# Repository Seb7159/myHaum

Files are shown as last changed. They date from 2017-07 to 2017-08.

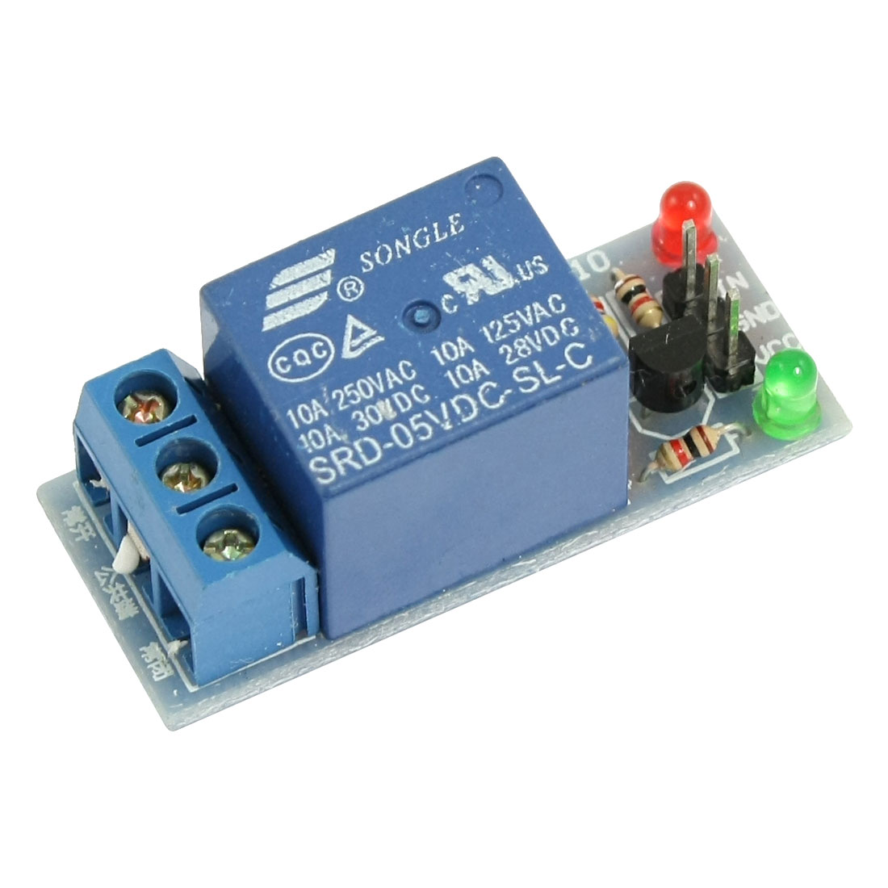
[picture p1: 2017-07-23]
web/form/map/img/9.jpg

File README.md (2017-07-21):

# myHaum

A project which adds tons of sensors in one product in order to serve one's home security.

## Getting Started

These instructions will get you a copy of the project up and running on your local Arduino micro-controller for development and testing purposes. See deployment for notes on how to deploy the project on a live system.

### Prerequisites

What things you need to install the software and how to install them

```
Arduino IDE
Arduino Mega 2560 micro-controller
WinSCP/Total Commander(FTP client)
Sublime text(optional)
```

### Installing

A step by step series of examples that tell you have to get a development env running

Add the sensors needed (those you can observe in the code)

```
DHT11
MQ2 Gas sensor
Photoresistor
PIR Motion sensor
LCD display
2 buttons
ESP8266-01 WiFi module
Passive buzzer
```

Make sure you edit the WiFi name and password 

```
Default WiFi name: H218N
Default WiFi pass: certificat
```

Put the /web files on your server

```
display.php
AppDisplay.php
/get files
```

IMPORTANT! Don't forget to change the passwords and the usernames to yours 

Hopefully this will work out for you. 

## Running the tests

Test it by keeping it on for as long as you want. 

### Break down into end to end tests

Tests are for finding bugs during the using period of the product, including the web applications.

## Deployment

To deploy the arduino part, you need to download the folder /temp (or /light), connect your Arduino with the connected sensors to the pins you have in the source code, then Run it by pressing the Arduino IDE button. 

To deploy the server files, connect to your server using a FTP program (I use WinSCP or Total Commander) and upload them there. 

## Built With

* [Arduino](https://www.arduino.cc/) - The micro-controller framework used
* [ESP8266](https://espressif.com/en/products/hardware/esp8266ex/overview) - Used to send data to the SQL server thorugh the ESP8266-01 module
* [Fixed table header](https://codepen.io/nikhil8krishnan/full/WvYPvv/) - Design for tables insine the display application 
* [NodeMCU firmware](https://github.com/nodemcu/nodemcu-firmware) - Big parts of code from the light's .ino source 
* [Codrops](https://github.com/nodemcu/codrops) - Main website was created using several ideas of his, realised for the front-end part (ButtonComponentMorph,MorphingBackgroundShapes,FullscreenForm,InteractivePoints) 

## Versioning

We use [GitHub](http://github.com/) for versioning. For the versions available, see the commits from this project (https://github.com/Seba7159/myHaum). 

## Authors

* **Sebastian Stanici** - *Initial work* - [Seba7159](https://github.com/Seba7159)

## License

This project is licensed under the MIT License - see the [LICENSE.md](LICENSE.md) file for details

## Acknowledgments

* One's name who finds bug fixes and contribues will have his name on the contributors list
* Was inspired by all the news following the problems with companies spying on clients, this project is for one's own use and myHaum team will never use your data, keeping it safe and secure

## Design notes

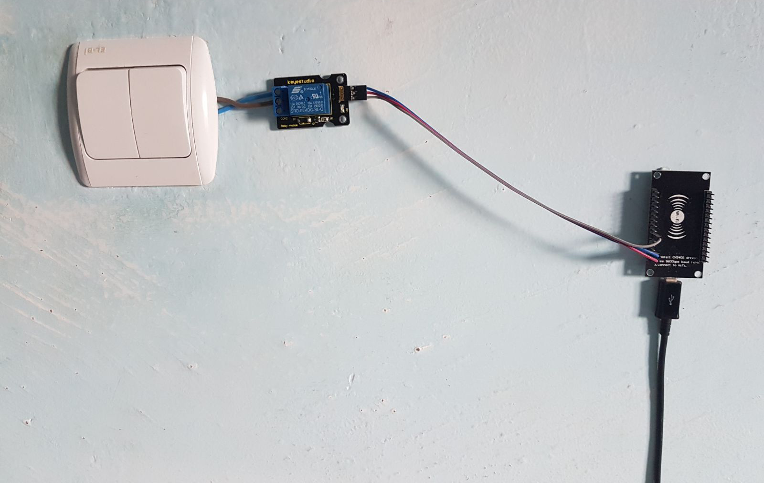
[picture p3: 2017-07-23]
web/form/map/img/map2.png

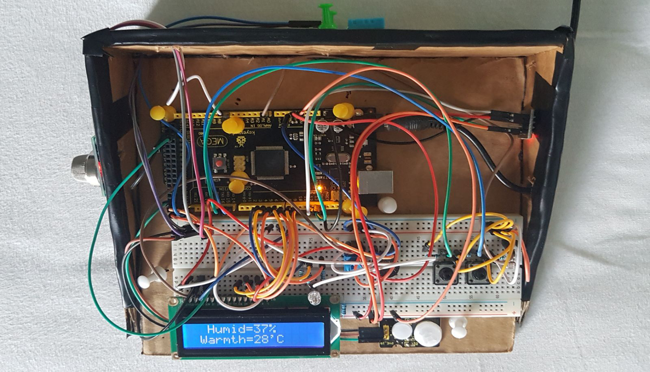
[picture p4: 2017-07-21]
web/form/map/img/map.png

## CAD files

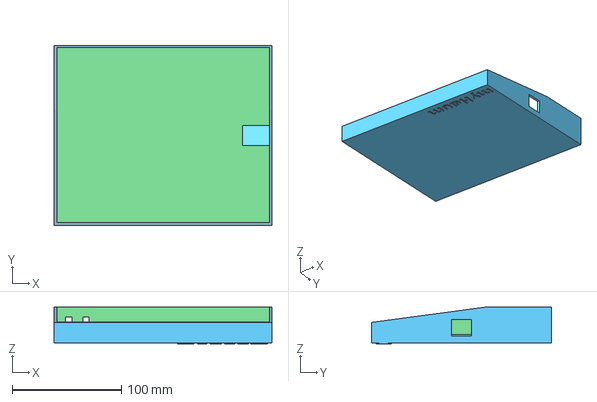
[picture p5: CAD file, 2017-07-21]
3Dprint/myHaum3DPrint1703303DBuilder.3mf
200.0 x 165.0 x 33.9 mm

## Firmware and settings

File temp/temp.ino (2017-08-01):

#include <Arduino.h>                   // the libraries 
#include <SoftwareSerial.h>
#include <ESP8266_Simple.h>
#include <LiquidCrystal.h> 
#include <DHT.h> 

#define DEBUG 1                         // if DEBUG is 1, the arduino will print data on Serial 

#define PHOTOpin A0                     // analog photoresistor 
#define GASpin A7                       // analog gas 
#define PIRsensorPin 24                 // digital PIR  
#define pBlu 3                          // digital blue LED 
#define pGrn 4                          // digital green LED
#define pRed 5                          // digital red LED 
#define ESP8266_SSID  "H218N"           // WiFi SSID
#define ESP8266_PASS  "certificat"      // WiFi Password
#define RXpinSEND 12                    // ESP-01 wifiSEND module TX
#define TXpinSEND 13                    // ESP-01 wifiSEND module RX 
#define RELAYbutton 15                  // digital switch 1
#define ALARMbutton 14                  // digital switch 2 
#define DHTpin 21                       // digital temp sensor  
#define BUZZpin 22                      // digital buzzer 

#define REFRESHupload 30                // seconds to upload data to database / to be changed to 15 min

LiquidCrystal lcd(11, 10, 6, 7, 8, 9);  // actual pins for LCD displaying content 
ESP8266_Simple wifiSEND( RXpinSEND, TXpinSEND); 
DHT dht( DHTpin, DHT11); 

byte doo[8] = {                         // set 7 frames of an animation in a LCD square when loading                 
  B00000,
  B00000,
  B00000,
  B00000,
  B00000,
  B10000,
  B11000,
};
byte re[8] = {
  B00000,
  B00000,
  B00000,
  B10000,
  B11000,
  B11100,
  B11110,
};
byte mi[8] = {
  B00000,
  B00000,
  B10000,
  B11000,
  B11100,
  B11100,
  B11111,
};
byte fa[8] = {
  B00000,
  B10000,
  B11000,
  B11100,
  B11110,
  B11111,
  B11111,
};
byte sol[8] = {
  B10000,
  B11000,
  B11100,
  B11110,
  B11111,
  B11111,
  B11111,
};
byte la[8] = {
  B11100,
  B11110,
  B11111,
  B11111,
  B11111,
  B11111,
  B11111,
};
byte si[8] = {
  B11111,
  B11111,
  B11111,
  B11111,
  B11111,
  B11111,
  B11111,
};
byte deg[8] = {
  B000111,
  B00101,
  B00111,
  B00000,
  B00000,
  B00000,
  B00000,
};









void setup(){
  lcd.createChar(1,doo);                  // create the animation frames by the micro-controller 
  lcd.createChar(2,re); 
  lcd.createChar(3,mi); 
  lcd.createChar(4,fa); 
  lcd.createChar(5,sol); 
  lcd.createChar(6,la); 
  lcd.createChar(7,si);
  lcd.createChar(8,deg); 
  
  lcd.begin(16, 2);                   
  lcd.setCursor(0,0); 
  lcd.print("Loading...             "); 
  
  int loadTime = 0;                       // begin animation 
  loadScreen(loadTime); loadTime++;  
  pinMode(pRed, OUTPUT);                  // set pin layout for arduino sending input and obtaining output 
  pinMode(pGrn, OUTPUT); 
  pinMode(pBlu, OUTPUT); 
  pinMode(PIRsensorPin,INPUT); 
  pinMode(ALARMbutton,INPUT); 
  pinMode(RELAYbutton,INPUT); 
  pinMode(BUZZpin, OUTPUT); 
  Serial.begin(9600); 
  wifiSEND.begin(9600); loadScreen(loadTime); loadTime++;                  // start WiFi module 
  

  lcd.setCursor(0,0); lcd.print("Resetting...             ");
  for( loadTime = 2 ; loadTime < 6; ++loadTime)
    loadScreen(loadTime); 

  char bufferr[300]; 
  wifiSEND.sendCommand(F("AT"), bufferr, sizeof(bufferr)); delay(50); 
  if(DEBUG) 
    Serial.println(bufferr);

  for( loadTime = 6 ; loadTime < 7; ++loadTime)
    loadScreen(loadTime); 

    
  wifiSEND.sendCommand(F("AT+CWJAP?"), bufferr, sizeof(bufferr));
  delay(100); 
  if(DEBUG){ 
    Serial.println(bufferr);
    Serial.println(ESP8266_SSID);     
  }

  for( loadTime = 7 ; loadTime < 10; ++loadTime)
    loadScreen(loadTime); 

  if(bufferr[0]!=ESP8266_SSID[0] || bufferr[1]!=ESP8266_SSID[1] || bufferr[2]!=ESP8266_SSID[2]){          // test if the ESP is already connected to previous WiFi 
  wifiSEND.sendCommand(F("AT+RST"), bufferr, sizeof(bufferr));                 // reset WiFi module 
  delay(2000); 
  wifiSEND.setupAsWifiStation(ESP8266_SSID, ESP8266_PASS, &Serial);            // connect to the WiFi with the set ssid and password 
  delay(5000); 
  }
  
  lcd.setCursor(0,0); lcd.print("Connecting...             "); 
  for( loadTime = 10 ; loadTime < 16; ++loadTime)
    loadScreen(loadTime); 
  lcd.setCursor(0,1); 
  lcd.print(" Ready!            ");
  delay(800); 
}








int alarm=0,lightBulb=0;                                                   // set booleans for alarm and lightBulb if they are on/off 
unsigned long WIFIupload = -REFRESHupload ,LASTmotion = 0;                 // set timeout for wifi uploading and last motion sensed 




void ifPressButton(){                                       // function for seeing if rhe buttons are pressed 
  if(digitalRead(ALARMbutton)){                                                 // event if alarm button(2) is pushed 
    alarm++; alarm=alarm%2; 
    if(DEBUG) Serial.print("Alarm is "); if(DEBUG) Serial.println(alarm);  
    if(alarm){
      
      lcd.setCursor(0,0); lcd.print("House will be         "); 
      lcd.setCursor(0,1); lcd.print(" armed in         "); 
      delay(400); 
      
      for( int i = 19 ; i>=0 ; --i ){
        lcd.setCursor(12,1);
        if(i<10) lcd.setCursor(11,1);
        lcd.print(i); lcd.print("         "); 

        setColor(40,0,0);
        delay(100); 
        setColor(0,0,0); 
        int ok=0; 
        
        for(int i=0;i<9;i++){
          if(digitalRead(ALARMbutton)){
            alarm++; alarm=alarm%2; 
            if(DEBUG) Serial.print("Alarm is "); if(DEBUG) Serial.println(alarm);  
            ok=1; 
            break; 
          }
          delay(100); 
        }
        if(ok==1)
          break; 
      }
      if(alarm){
        lcd.setCursor(0,0); 
        lcd.print("House is now       "); 
        lcd.setCursor(0,1); 
        lcd.print("      ARMED!          "); 
        setColor(255,0,0); 
        }
      else{
        lcd.setCursor(0,0); 
        lcd.print("House is now       "); 
        lcd.setCursor(0,1); 
        lcd.print("    UNARMED!           "); 
        setColor(0,0,255); 
      }
    }
    else{
      lcd.setCursor(0,0); 
      lcd.print("House is now       "); 
      lcd.setCursor(0,1); 
      lcd.print("    UNARMED!          "); 
      setColor(0,0,255); 
    } 
    delay(2000); 
    setColor(0,0,0); 
  }
  


  if(digitalRead(RELAYbutton)){                                                                // event if light bulb button(1) is pushed 
    lightBulb++; lightBulb=lightBulb%2; 
    if(DEBUG) Serial.print("The light bulb is "); if(DEBUG) Serial.println(lightBulb); 
    if(lightBulb){
      lcd.setCursor(0,0); 
      lcd.print("Light bulb                "); 
      lcd.setCursor(0,1); 
      lcd.print("         ON!          "); 
      setColor(255,255,255); 
    }
    else{
      lcd.setCursor(0,0); 
      lcd.print("Light bulb          "); 
      lcd.setCursor(0,1); 
      lcd.print("         OFF!     "); 
      setColor(0,0,0); 
    }
    delay(900); 
  }  
}


void loop()                                                                // start a new cycle
{  
  if(DEBUG) Serial.println("Starting new cycle");                           


  
  if(DEBUG) Serial.print("Gas value is ");                                 // read gas and alarm if gas levels are too high ( over 45% = gas leaks, over 50% = hazardous environment ) 
  if(DEBUG) Serial.println(analogRead(GASpin)); 
  if(analogRead(GASpin)>450){
      if(analogRead(GASpin)>500){
        lcd.setCursor(0,0); 
        lcd.print(" WARNING! GAS"); 
        lcd.setCursor(0,1); 
        lcd.print("  LEVELS EXCEEDED!"); 
        tone(BUZZpin, 2000, 500); 
      }
      else{
        lcd.setCursor(0,0); 
        lcd.print(" WARNING! Gas"); 
        lcd.setCursor(0,1); 
        lcd.print("  leaks detected!"); 
      }

      char buffer[250];                                                                                  // send WiFi data in case of gas leaks (>25% gas levels)

      memcpy(buffer, 0, sizeof(buffer));     
      strncpy_P(buffer, PSTR("/get/getgas.php?p=abc"), sizeof(buffer)-1);
     
      strncpy_P(buffer+strlen(buffer), PSTR("&lastg="), sizeof(buffer)-strlen(buffer)-1);
      ltoa(analogRead(GASpin), buffer+strlen(buffer), 10); 
        
      if(DEBUG) Serial.print("Requesting GAS");
      if(DEBUG) Serial.print(buffer);
      if(DEBUG) Serial.print(": ");
      
      unsigned int httpResponseCode = 
        wifiSEND.GET
        (
          F("86.123.250.85"),     
          80,                     
          buffer,                 
          sizeof(buffer),         
          F("seba.tm-edu.ro"), 
          2                       
                                   
                                  
        );
  
    if(httpResponseCode == 200 || httpResponseCode == ESP8266_OK){
      if(DEBUG) Serial.println("OK");
      if(DEBUG) Serial.println(buffer);
    }
    else
      if(httpResponseCode < 100) 
        wifiSEND.debugPrintError((byte)httpResponseCode, &Serial);
      else{
        if(DEBUG) Serial.print("HTTP Status ");
        if(DEBUG) Serial.println(httpResponseCode);
      }     
   
     delay(1000); 
  }
  else
    noTone(BUZZpin); 


  ifPressButton();


  if(digitalRead(PIRsensorPin)){                                                                 // event motion sense 
    if(DEBUG) Serial.println("Somebody is in this area!"); 
    LASTmotion=millis()/1000; 
    
    if(alarm==1){
      char buffer[250]; 
    
      memcpy(buffer, 0, sizeof(buffer));     
      strncpy_P(buffer, PSTR("/get/getmotion.php?p=abc"), sizeof(buffer)-1);
     
      strncpy_P(buffer+strlen(buffer), PSTR("&lastm="), sizeof(buffer)-strlen(buffer)-1);
      ltoa(millis()/1000, buffer+strlen(buffer), 10); 
        
      if(DEBUG) Serial.print("Requesting MOTION");
      if(DEBUG) Serial.print(buffer);
      if(DEBUG) Serial.print(": ");
      
      unsigned int httpResponseCode = 
        wifiSEND.GET
        (
          F("86.123.250.85"),     
          80,                     
          buffer,                 
          sizeof(buffer),         
          F("seba.tm-edu.ro"), 
          2                       
                                   
                                  
        ); 
      
      if(httpResponseCode == 200 || httpResponseCode == ESP8266_OK){
        if(DEBUG) Serial.println("OK");
        if(DEBUG) Serial.println(buffer);
      }
      else
        if(httpResponseCode < 100) 
          wifiSEND.debugPrintError((byte)httpResponseCode, &Serial);
        else{
          if(DEBUG) Serial.print("HTTP Status ");
          if(DEBUG) Serial.println(httpResponseCode);
        }
    }  
  }












  if(DEBUG){                                                 // print data to Serial if DEBUG = 1
    Serial.println("Brightness: "); // brightness   
    Serial.println(analogRead(PHOTOpin));  
    Serial.println(); 
    Serial.print("Temperature = "); // DHT 
    Serial.println(dht.readTemperature());
    Serial.print("Humidity = ");
    Serial.println(dht.readHumidity()); 
    Serial.println(); 
  }






  
  if(lightBulb==0){                                                                                // display different data wheter the light bulb is on or off 
    lcd.setCursor(0,0); 
    lcd.print("  Humid="); lcd.print((int)dht.readHumidity()); lcd.print("%            ");  
    lcd.setCursor(0,1); 
    lcd.print(" Warmth="); lcd.print((int)dht.readTemperature()); lcd.write(byte(8)); lcd.println("C            ");
  }
  else{
    lcd.setCursor(0,0); 
    lcd.print("Brightness: ");  
    lcd.print(analogRead(PHOTOpin)); 
    lcd.print("               "); 
    lcd.setCursor(0,1); 
    lcd.print("Gas: "); 
    lcd.print(analogRead(GASpin)); lcd.print("               "); 
  }









  if(WIFIupload+REFRESHupload<millis()/1000){                                                // send all the data from all the sensor over WiFi to SQL database  
    char buffer[250]; 
    
      memcpy(buffer, 0, sizeof(buffer));     
      strncpy_P(buffer, PSTR("/get/get.php?p=abc"), sizeof(buffer)-1);
     
      strncpy_P(buffer+strlen(buffer), PSTR("&temp="), sizeof(buffer)-strlen(buffer)-1);
      ltoa((int)dht.readTemperature(), buffer+strlen(buffer), 10); 

      strncpy_P(buffer+strlen(buffer), PSTR("&hum="), sizeof(buffer)-strlen(buffer)-1);
      ltoa((int)dht.readHumidity(), buffer+strlen(buffer), 10); 

      strncpy_P(buffer+strlen(buffer), PSTR("&gas="), sizeof(buffer)-strlen(buffer)-1);
      ltoa(analogRead(GASpin), buffer+strlen(buffer), 10); 

      strncpy_P(buffer+strlen(buffer), PSTR("&light="), sizeof(buffer)-strlen(buffer)-1);
      ltoa(analogRead(PHOTOpin), buffer+strlen(buffer), 10); 

      strncpy_P(buffer+strlen(buffer), PSTR("&ms="), sizeof(buffer)-strlen(buffer)-1);
      ltoa(millis()/1000, buffer+strlen(buffer), 10); 

      strncpy_P(buffer+strlen(buffer), PSTR("&lmdbu="), sizeof(buffer)-strlen(buffer)-1);
      ltoa(LASTmotion, buffer+strlen(buffer), 10); 

      strncpy_P(buffer+strlen(buffer), PSTR("&alarm="), sizeof(buffer)-strlen(buffer)-1);
      ltoa(alarm, buffer+strlen(buffer), 10); 
        
      if(DEBUG) Serial.print("Requesting UPLOAD");
      if(DEBUG) Serial.print(buffer);
      if(DEBUG) Serial.print(": ");
      
      unsigned int httpResponseCode = 
        wifiSEND.GET
        (
          F("86.123.250.85"),     
          80,                     
          buffer,                 
          sizeof(buffer),         
          F("seba.tm-edu.ro"), 
          2                       
        ); 
      
      if(httpResponseCode == 200 || httpResponseCode == ESP8266_OK){
        if(DEBUG) Serial.println("OK");
        if(DEBUG) Serial.println(buffer);
      }
      else
        if(httpResponseCode < 100) 
          wifiSEND.debugPrintError((byte)httpResponseCode, &Serial);
        else{
          if(DEBUG) Serial.print("HTTP Status ");
          if(DEBUG) Serial.println(httpResponseCode);
        }
    WIFIupload=millis()/1000; 
  }





  
  if(DEBUG) 
    for(int i=0;i<30;i++) Serial.println();                   // clean screen of Serial 


  for(int i=0;i<10;i++){                                      // 2 second pause after cycle is over for avoiding overheating and over-use of electricity
    ifPressButton();
    delay(200);
  }                                                            
}                                                             // end of cycle 












void setColor(int red, int green, int blue)                  // function to set rgb color of light bulb 
{
  digitalWrite(pRed, red);
  digitalWrite(pGrn, green);
  digitalWrite(pBlu, blue);  
}








void loadScreen(int j){                                     // function for animation purpose 
  for(int i=1;i<=7;i++){
    lcd.setCursor(j,1);
    lcd.write(byte(i));  
    delay(80-j*3); 
  }
}

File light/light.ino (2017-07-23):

#include <ESP8266WiFi.h>                                          // libraries
#include <WiFiClient.h>
#include <ESP8266WebServer.h>
#include <ESP8266mDNS.h>

const char* ssid = "H218N";                                       // set WiFi ssid and pass
const char* password = "certificat";

// 13 is pin 7 
// 16 is pin 0 

ESP8266WebServer server(80);                                      // set server port 

const int led = 13;                                               // set led pin 
int onff = 0, door = 0;                                           // set booleans for dor and on/off led 

void handleRoot() {                                               // root page 
  server.send(200, "text/plain", "Hello Seba!");
}

void handleOffline() {                                            // light control page 
  onff++; onff%=2;
  if(onff==1)
    server.send(200, "text/plain", "Light ON!");
  else
    server.send(200, "text/plain", "Light OFF!");
  digitalWrite(13, onff);
}

void handleNotFound(){                                            // error 404 not found page 
  digitalWrite(led, 1);
  String message = "File Not Found\n\n";
  message += "URI: ";
  message += server.uri();
  message += "\nMethod: ";
  message += (server.method() == HTTP_GET)?"GET":"POST";
  message += "\nArguments: ";
  message += server.args();
  message += "\n";
  for (uint8_t i=0; i<server.args(); i++){
    message += " " + server.argName(i) + ": " + server.arg(i) + "\n";
  }
  server.send(404, "text/plain", message);
  digitalWrite(led, 0);
}

void setup(){                                                       // setup function with pin setup 
  pinMode(led, OUTPUT);
  digitalWrite(led, 0);
  Serial.begin(115200);
  WiFi.begin(ssid, password);                                       // start WiFi module 
  Serial.println("");

  // Wait for connection
  while (WiFi.status() != WL_CONNECTED) {
    delay(500);
    Serial.print(".");
  }
  Serial.println("");
  Serial.print("Connected to ");
  Serial.println(ssid);
  Serial.print("IP address: ");
  Serial.println(WiFi.localIP());



  Serial.print("connecting to ");
  Serial.println("seba.tm-edu.ro");
  
  WiFiClient client;
  const int httpPort = 80;
  if (!client.connect("seba.tm-edu.ro", httpPort)) {                      // update local ip to SQL database 
    Serial.println("connection failed");
    return;
  }
  
  String url = "/";
  url += "get/getIP.php";
  url += "?p=";
  url += "abc";
  url += "&ip=";
  url += String(WiFi.localIP()[3]); 
  
  Serial.print("Requesting URL: ");
  Serial.println(url);
  
  // This will send the request to the server
  client.print(String("GET ") + url + " HTTP/1.1\r\n" +
               "Host: " + "seba.tm-edu.ro" + "\r\n" + 
               "Connection: close\r\n\r\n");
  unsigned long timeout = millis();
  while (client.available() == 0) {
    if (millis() - timeout > 5000) {
      Serial.println(">>> Client Timeout !");
      client.stop();
      return;
    }
  }

  Serial.println("\n connection stopped"); 





  if (MDNS.begin("esp8266")) {
    Serial.println("MDNS responder started");
  }
                                                                    // set all pages that can be opened starting with root page, switch trigger, test and error 404 page
  server.on("/", handleRoot);

  server.on("/offline", handleOffline);

  server.on("/inline", [](){
      server.send(200, "text/plain", "this works as well");
  });

  server.onNotFound(handleNotFound);

  server.begin();
  Serial.println("HTTP server started");
}

void loop(){                                                        // cycle of WiFi module testing whether the page were entered or not 
  server.handleClient();
}

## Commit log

2017-07-21 First test on Arduino Mega 2560
    This is the first code I tried using a DHT11 Temperature and Humidity sensor on the main controller, the Arduino Mega 2560.
    - mid January 2017
2017-07-21 Update featuring optimisations
    The next three months, I had to create a website for my project with a well-based front-end and back-end, test the product in my room almost daily, fix the bugs and take my exams.
    This is the piece I updated from the last source code with further optimisation and bug fixes.
    In the event of winning the competition in the county, I will have to do more upgrades to it, but we'll see what the future gives in.
    - 19th of April 2017
    [temp.ino]
2017-07-21 Light product
    In the meantime, I had another idea of creating a product which handles light switches, using a NodeMCU micro-controller and a relay.
2017-07-21 3D printed case
    As for living in the year of 2017 and 3D printing slowly becomes a habitual thing in one's life, I created this piece of framework for the main myHaum device. First framework was designed as cheap as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
    [myHaum3DPrint1703303DBuilder.3mf]
2017-07-21 3D print case updated
    In order to reduce the cost from 120$ to somewhere around ~40$, the item was reduced in its weight in record time. More updates to it are to come, following to become way cheaper, maybe even 10-15$, 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
    [myHaum3DPrint1703303DBuilder.3mf]
2017-07-21 Updated name
    [myHaum3DPrint1703303DBuilder.3mf]
2017-07-23 Comments and updates
    Had to comment most of my main Arduino code and the light Arduino code. Updated it too, and brought another map page for the light Arduino with the NodeMCU on it.
2017-07-30 Faster myHaum and gas calibration
    Had to calibrate the gas sensor because it was always feeling gas when the parameters weren't set right. Meanwhile, we found a hack in which the ESP WiFi module connects automatically to the last WiF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
2017-08-01 Added some pluses to main Arduino code
